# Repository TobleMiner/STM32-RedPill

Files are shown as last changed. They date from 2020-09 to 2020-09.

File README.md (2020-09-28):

STM32 RedPill
=============

The RedPill, for when you realize the BluePill just doesn't cut it.

The RedPill is designed as a more powerful drop-in replacement for the
BluePill. While .1" wider the RedPill is fully pin-compatible to the
BluePill.  
The following table summarizes the most important differences between
RedPill and BluePill:  
| | RedPill | BluePill |
|---|---|---|
| MCU | STM32F722REC6 | STM32F103C8T6 |
| ARM core | Cortex-M7 | Cortex-M3 |
| Max system clock | 216MHz | 72MHz |
| Flash | 256kB | 128kB |
| SRAM | 256kB | 20kB |
| Programming | DFU, SWD | SWD |
| USB connector | USB Type C | Micro USB Type B |
| SD card | MicroSD | - |
| LEDs | 5 | 1 |

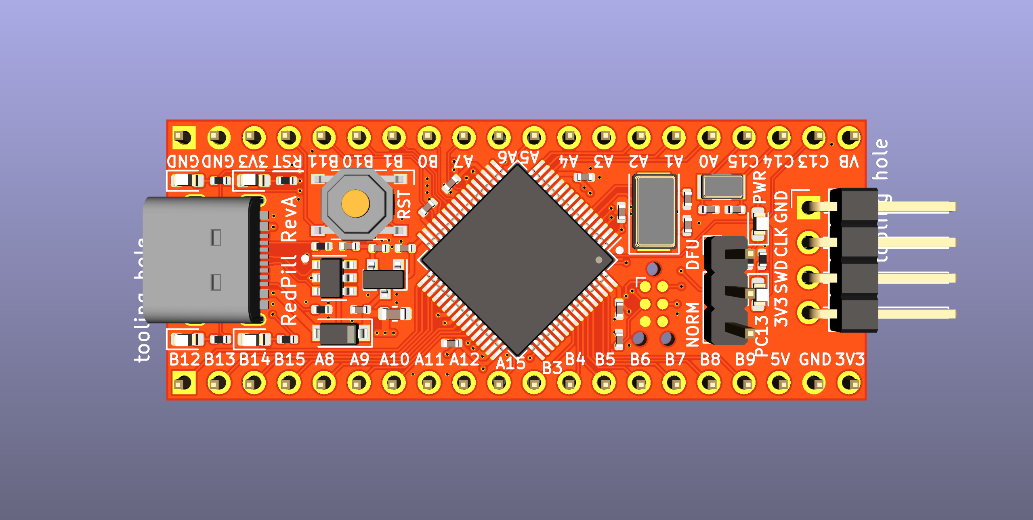
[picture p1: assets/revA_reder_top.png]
PCB top


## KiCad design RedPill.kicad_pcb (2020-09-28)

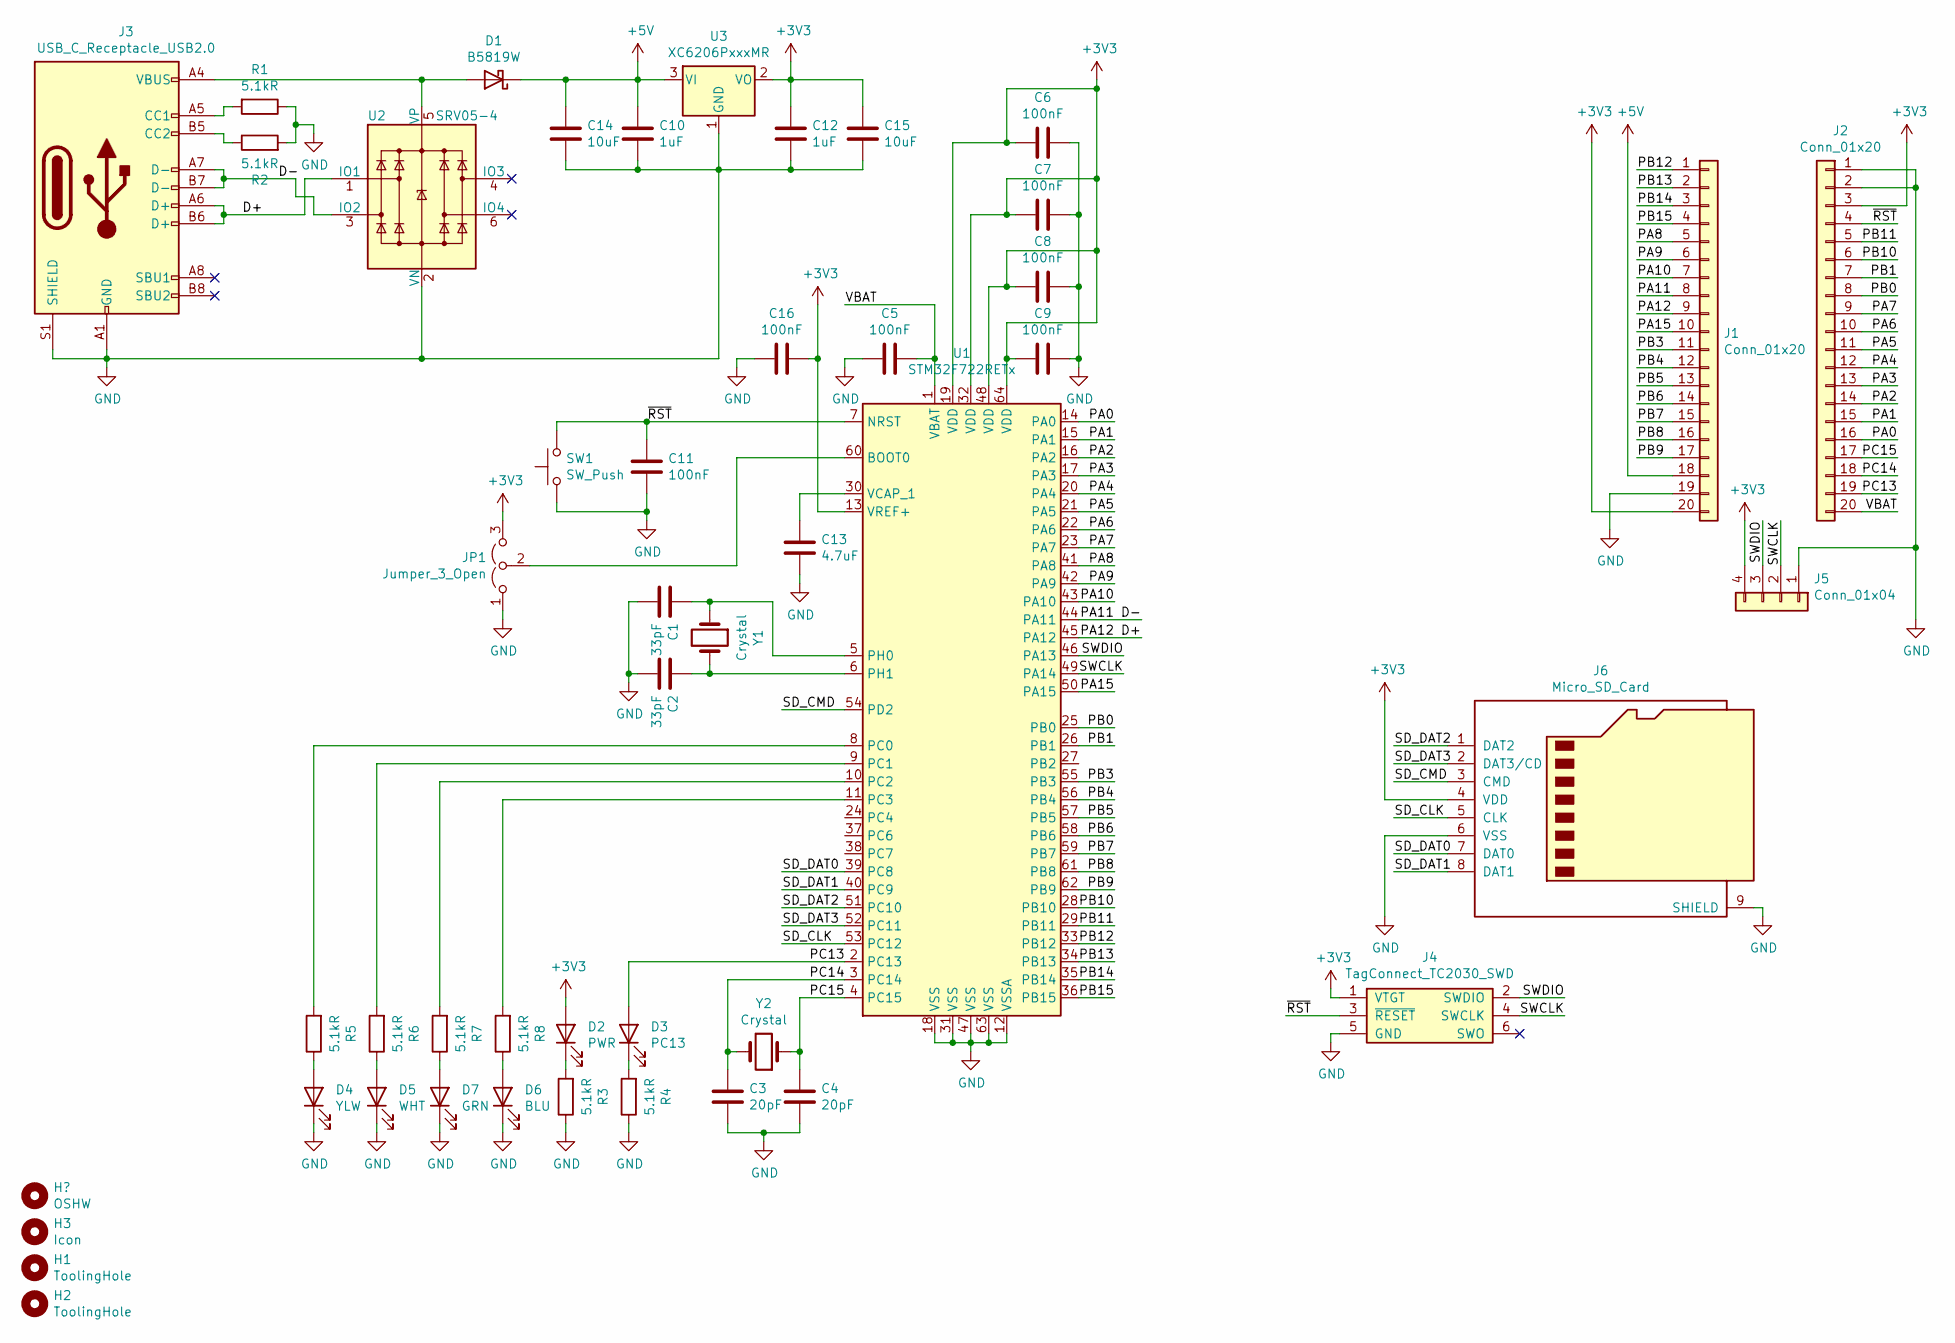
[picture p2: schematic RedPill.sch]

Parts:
C1, C2: 33pF; C_0402_1005Metric; LCSC C1562
C3, C4: 20pF; C_0402_1005Metric; LCSC C1554
C5, C6, C7, C8, C9, C11, C16: 100nF; C_0402_1005Metric; LCSC C1525
C10, C12: 1uF; C_0402_1005Metric; LCSC C52923
C13: 4.7uF; C_0402_1005Metric; LCSC C23733
C14: 10uF; C_0603_1608Metric; LCSC C19702
C15: 10uF; C_0402_1005Metric; LCSC C15525
D1: B5819W; D_SOD-123; LCSC C8598
D2: PWR; LED_0603_1608Metric; LCSC C2286
D3: PC13; LED_0603_1608Metric; LCSC C2286
D4: YLW; LED_0603_1608Metric; LCSC C72038
D5: WHT; LED_0603_1608Metric; LCSC C2290
D6: BLU; LED_0603_1608Metric; LCSC C72041
D7: GRN; LED_0603_1608Metric; LCSC C72043
H1, H2: ToolingHole; ToolingHole_JLCSMT
H3: Icon; pill
J1, J2: Conn_01x20; PinHeader_1x20_P2.54mm_Vertical
J3: USB_C_Receptacle_USB2.0; USB_C_Receptacle_Palconn_UTC16-G
J4: TagConnect_TC2030_SWD; Tag-Connect_TC2030-IDC-NL_2x03_P1.27mm_Vertical
J5: Conn_01x04; PinHeader_1x04_P2.54mm_Horizontal
J6: Micro_SD_Card; XUNPU_TF.104
JP1: Jumper_3_Open; PinHeader_1x03_P2.54mm_Vertical
R1, R2, R3, R4, R5, R6, R7, R8: 5.1kR; R_0402_1005Metric; LCSC C25905
SW1: SW_Push; TS-1187A-X-X-X; LCSC C318889
U1: STM32F722RETx; LQFP-64_10x10mm_P0.5mm; LCSC C118207
U2: SRV05-4; SOT-23-6; LCSC C85364
U3: XC6206PxxxMR; SOT-23; LCSC C5446
Y1: Crystal; Crystal_SMD_5032-2Pin_5.0x3.2mm; LCSC C115962
Y2: Crystal; Crystal_SMD_3215-2Pin_3.2x1.5mm; LCSC C32346

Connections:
+3V3: C6.1, C7.1, C8.1, C9.1, C12.1, C15.1, C16.2, D2.2 (A), J1.20, J2.3, J4.1 (VTGT), J5.4, J6.4 (VDD), JP1.3 (B), U1.13 (VREF+), U1.19 (VDD), U1.32 (VDD), U1.48 (VDD), U1.64 (VDD), U3.2 (VO)
+5V: C10.1, C14.1, D1.1 (K), J1.18, U3.3 (VI)
/D+: J1.9, J3.A6 (D+), J3.B6 (D+), U1.45 (PA12), U2.1 (IO1)
/D-: J1.8, J3.A7 (D-), J3.B7 (D-), U1.44 (PA11), U2.3 (IO2)
/PA0: J2.16, U1.14 (PA0)
/PA1: J2.15, U1.15 (PA1)
/PA2: J2.14, U1.16 (PA2)
/PA3: J2.13, U1.17 (PA3)
/PA4: J2.12, U1.20 (PA4)
/PA5: J2.11, U1.21 (PA5)
/PA6: J2.10, U1.22 (PA6)
/PA7: J2.9, U1.23 (PA7)
/PA8: J1.5, U1.41 (PA8)
/PA9: J1.6, U1.42 (PA9)
/PA10: J1.7, U1.43 (PA10)
/PA15: J1.10, U1.50 (PA15)
/PB0: J2.8, U1.25 (PB0)
/PB1: J2.7, U1.26 (PB1)
/PB3: J1.11, U1.55 (PB3)
/PB4: J1.12, U1.56 (PB4)
/PB5: J1.13, U1.57 (PB5)
/PB6: J1.14, U1.58 (PB6)
/PB7: J1.15, U1.59 (PB7)
/PB8: J1.16, U1.61 (PB8)
/PB9: J1.17, U1.62 (PB9)
/PB10: J2.6, U1.28 (PB10)
/PB11: J2.5, U1.29 (PB11)
/PB12: J1.1, U1.33 (PB12)
/PB13: J1.2, U1.34 (PB13)
/PB14: J1.3, U1.35 (PB14)
/PB15: J1.4, U1.36 (PB15)
/PC13: D3.2 (A), J2.19, U1.2 (PC13)
/PC14: C3.1, J2.18, U1.3 (PC14), Y2.2
/PC15: C4.1, J2.17, U1.4 (PC15), Y2.1
/SD_CLK: J6.5 (CLK), U1.53 (PC12)
/SD_CMD: J6.3 (CMD), U1.54 (PD2)
/SD_DAT0: J6.7 (DAT0), U1.39 (PC8)
/SD_DAT1: J6.8 (DAT1), U1.40 (PC9)
/SD_DAT2: J6.1 (DAT2), U1.51 (PC10)
/SD_DAT3: J6.2 (DAT3/CD), U1.52 (PC11)
/SWCLK: J4.4 (SWCLK), J5.2, U1.49 (PA14)
/SWDIO: J4.2 (SWDIO), J5.3, U1.46 (PA13)
/VBAT: C5.2, J2.20, U1.1 (VBAT)
/~RST: C11.1, J2.4, J4.3 (~RESET), SW1.2, U1.7 (NRST)
GND: C1.2, C2.2, C3.2, C4.2, C5.1, C6.2, C7.2, C8.2, C9.2, C10.2, C11.2, C12.2, C13.2, C14.2, C15.2, C16.1, D4.1 (K), D5.1 (K), D6.1 (K), D7.1 (K), J1.19, J2.1, J2.2, J3.A1 (GND), J3.A12 (GND), J3.B1 (GND), J3.B12 (GND), J3.S1 (SHIELD), J4.5 (GND), J5.1, J6.6 (VSS), J6.9 (SHIELD), JP1.1 (A), R1.1, R2.2, R3.1, R4.1, SW1.1, U1.12 (VSSA), U1.18 (VSS), U1.31 (VSS), U1.47 (VSS), U1.63 (VSS), U2.2 (VN), U3.1 (GND)
unnamed: C1.1, U1.5 (PH0), Y1.1
unnamed: C2.1, U1.6 (PH1), Y1.2
unnamed: C13.1, U1.30 (VCAP_1)
unnamed: D1.2 (A), J3.A4 (VBUS), J3.A9 (VBUS), J3.B4 (VBUS), J3.B9 (VBUS), U2.5 (VP)
unnamed: D2.1 (K), R3.2
unnamed: D3.1 (K), R4.2
unnamed: D4.2 (A), R5.1
unnamed: D5.2 (A), R6.1
unnamed: D6.2 (A), R8.1
unnamed: D7.2 (A), R7.1
unnamed: J3.A5 (CC1), R1.2
unnamed: J3.B5 (CC2), R2.1
unnamed: JP1.2 (C), U1.60 (BOOT0)
unnamed: R5.2, U1.8 (PC0)
unnamed: R6.2, U1.9 (PC1)
unnamed: R7.2, U1.10 (PC2)
unnamed: R8.2, U1.11 (PC3)

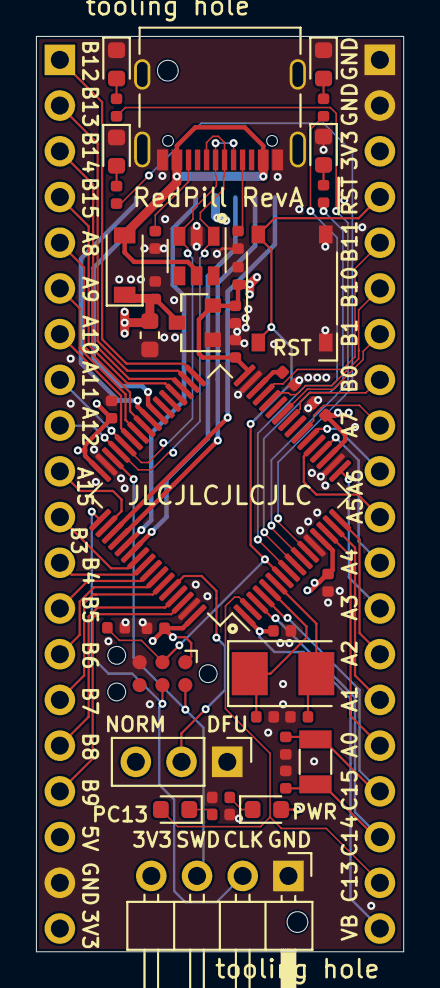
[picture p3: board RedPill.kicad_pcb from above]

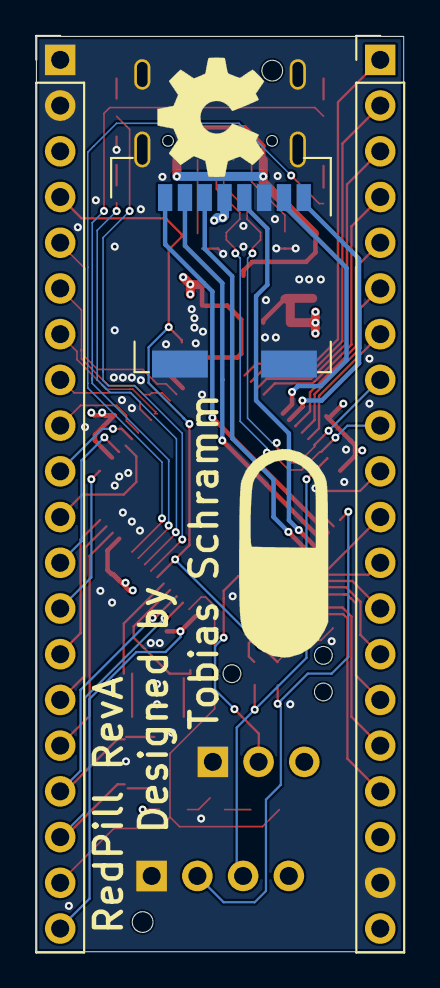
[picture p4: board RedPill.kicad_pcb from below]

Board: 4 copper layers, 20.4 x 50.9 mm, 48 parts (5 on the bottom side), 62 nets.

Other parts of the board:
H4: OSHW; OSHW-Symbol_6.7x6mm_SilkScreen

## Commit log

2020-09-28 Hide all fp references
    [RedPill.kicad_pcb]
2020-09-28 Route IOs
    [RedPill.kicad_pcb]
2020-09-28 Finish layout
    [RedPill.kicad_pcb, RedPill.sch]
2020-09-28 Add JLCSMT tooling holes
    [RedPill.kicad_pcb, RedPill.sch]
2020-09-28 Add silkscreen markings
    [RedPill.kicad_pcb, RedPill.sch]
2020-09-28 Add OSHW logo
    [RedPill.kicad_pcb, RedPill.sch]
2020-09-28 Add chip orientation markings
    [RedPill.kicad_pcb]
2020-09-28 Attach 5V pin to input capacitor
    [RedPill.kicad_pcb]
2020-09-28 Add LCSC partnumbers to all components
    Yes, even ones JLC can not populate
    [RedPill.sch]
